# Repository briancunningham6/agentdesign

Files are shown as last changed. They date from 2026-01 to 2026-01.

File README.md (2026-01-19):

# Coffee Grounds Compost Container

A 3D-printable modular container system for collecting and draining coffee grounds, designed with CadQuery.

## Overview

This project provides a complete coffee grounds collection system with:

- **Main Container Box** (200×150×150mm) - With sloped floor and threaded drain fitting
- **Lid with Handle** - Includes integrated Nespresso capsule scraper and storage groove
- **Drain Spout** - Threaded compression fitting with TPU gasket seal
- **French Press Scraper** - Bayonet-mount scraper for cleaning French press
- **Storage Scraper** - Compact scraper that stores in the lid handle groove

All parts are designed for FDM 3D printing in PLA or PETG (except TPU gasket).

## Project Structure

```
coffee-grounds-container/
├── CAD/                    # Generated 3D model files (STL/STEP)
│   ├── box.stl
│   ├── lid.stl
│   ├── drain_spout.stl
│   └── ...
├── scripts/                # Python generator scripts
│   ├── generate_all.py
│   ├── generate_box.py
│   ├── generate_drain_spout.py
│   └── ...
├── backend/                # Flask backend (optional web interface)
├── webapp/                 # React frontend (optional web interface)
├── generate_all.sh         # Generate all CAD files
├── start_webapp.sh         # Start web interface
└── README.md
```

## Quick Start

### Generate All Parts

```bash
./generate_all.sh
```

This generates all STL and STEP files in the `CAD/` directory.

### Generate Individual Parts

```bash
# Generate box and lid
/Users/user/miniforge3/envs/cq/bin/python scripts/generate_box.py

# Generate drain spout
/Users/user/miniforge3/envs/cq/bin/python scripts/generate_drain_spout.py

# Generate French press scraper
/Users/user/miniforge3/envs/cq/bin/python scripts/generate_french_press_scraper.py

# Generate storage scraper
/Users/user/miniforge3/envs/cq/bin/python scripts/generate_storage_scraper.py
```

## Parts to Print

### Main Components (PLA/PETG)
1. **box.stl** - Main container with threaded drain boss
2. **lid.stl** - Lid with handle and integrated capsule scraper (requires nail assembly)
3. **lid_scraper.stl** - Nespresso capsule scraper (bayonet mount, alternative design)
4. **drain_spout.stl** - Threaded drain spout with hex flange
5. **french_press_scraper.stl** - French press scraper with bayonet mount
6. **storage_scraper.stl** - Compact scraper for lid storage

### Seal Component (TPU)
7. **seal_ring.stl** - Gasket for drain spout (print in TPU/NinjaFlex)

### Additional Materials Required
8. **Metal brad nails** (for lid capsule scraper)
   - 8× 1.5mm diameter × 25-30mm long brad nails (18ga)
   - See [NAIL_ASSEMBLY_GUIDE.md](NAIL_ASSEMBLY_GUIDE.md) for assembly instructions

## Print Settings

**PLA/PETG parts:**
- Layer height: 0.2mm
- Infill: 30-50%
- Wall thickness: 4 perimeters
- Top/bottom layers: 5 layers
- Supports: None needed (all parts print support-free)

**TPU gasket:**
- Layer height: 0.2mm
- Infill: 100%
- Print slowly (20-30mm/s)

## Assembly

1. **Install nails in capsule scraper (integrated into lid):**
   - Press 8× 1.5mm brad nails into holes on scraper underside
   - Nail heads sit in countersunk sockets
   - See [NAIL_ASSEMBLY_GUIDE.md](NAIL_ASSEMBLY_GUIDE.md) for detailed instructions

2. **Attach drain spout:**
   - Place TPU seal ring in the flange groove
   - Thread spout into box boss from outside
   - Hand-tighten using hex flange

3. **Attach optional scrapers to lid:**
   - **Capsule scraper (separate):** Insert shaft, rotate 60° to lock bayonet
   - **French press scraper:** Same bayonet mechanism

4. **Store scrapers when not in use:**
   - Wedge storage scraper shaft into lid handle groove
   - French press scraper can also store in groove

## Features

### Box
- 200×150×150mm interior volume
- Sloped floor (2°) drains toward left wall
- M16×3 threaded boss for secure spout attachment
- Drainage channel guides liquid to drain
- Four rubber feet recesses for stability

### Lid
- Recessed fit prevents spills
- Integrated handle with tool storage groove
- Metal nail-insert Nespresso capsule scraper (underside, requires 8× brad nails)
- Bayonet socket for attachable scrapers

### Drain Spout
- 60mm extension reaches sink
- M16×3 threaded shaft with hand-tightenable hex flange
- TPU gasket creates watertight seal
- 8mm internal bore for liquid flow

### Scrapers
- **Capsule scraper (integrated):** 8 metal nails pierce foil, rotate to extract grounds
  - Requires assembly: press 1.5mm × 25-30mm brad nails into holes
  - Metal nails are much stronger than plastic pins
- **Capsule scraper (separate, bayonet mount):** Alternative bayonet-attachable version
- **French press:** Oblong blade reaches curved areas, bayonet mount
- **Storage:** Compact design stores in handle, friction ridge locks in place

## Design Files

All scripts generate both STL (for slicing) and STEP (for CAD editing) formats.

### Test Components

Generate fit-test coupons to verify tolerances before printing full parts:

```bash
/Users/user/miniforge3/envs/cq/bin/python scripts/generate_fit_test.py
```

This creates scaled-down test pieces to verify:
- Thread engagement (spout → box)
- Bayonet lock fit (scraper → lid)
- Seal compression

## Optional Web Interface

Start the interactive web designer:

```bash
./start_webapp.sh
```

Access at http://localhost:3000 to customize dimensions and regenerate parts.

## Requirements

- **CadQuery environment:** Python with CadQuery library
- **Conda environment:** `cq` (includes CadQuery)
- **Optional:** Node.js + Flask (for web interface)

## License

Open source - modify and share freely.

## Credits

Designed with CadQuery parametric CAD library.

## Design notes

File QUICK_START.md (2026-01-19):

# Quick Start Guide

## Coffee Grounds Compost Container

### What You Need

#### To Print:
1. 3D printer (FDM recommended, PLA or PETG)
2. TPU filament (small amount for gasket)

#### To Purchase:
1. **8× Brad nails** - 1.5mm diameter × 25-30mm length (18ga)
   - Available at any hardware store
   - Used for capsule scraper assembly
   - Cost: ~$3-5 for a box of 1000

#### Tools:
- Small hammer or rubber mallet
- Hex wrench or pliers (for spout installation)

---

## Step-by-Step Instructions

### 1. Generate CAD Files

```bash
cd "/Users/user/dev/3d Models"
./generate_all.sh
```

All STL files will be created in the `CAD/` directory.

### 2. Print All Parts

Print the following files from `CAD/`:

**Main parts (PLA/PETG):**
- `box.stl` - Main container (~6-8 hours)
- `lid.stl` - Lid with integrated scraper (~2-3 hours)
- `drain_spout.stl` - Drain fitting (~1 hour)
- `storage_scraper.stl` - Scraper for French press (~1 hour)
- `french_press_scraper.stl` - Alternative scraper (~1 hour)

**Seal (TPU):**
- `seal_ring.stl` - Gasket for drain (~15 minutes)

**Print Settings:**
- Layer height: 0.2mm
- Infill: 30-50%
- Supports: NONE (all parts designed support-free)

### 3. Assemble Capsule Scraper

**The lid has 8 holes on the underside that need metal nails inserted.**

1. Flip lid upside-down
2. Locate the 8 holes on the circular scraper base
3. Take 1.5mm × 25-30mm brad nails
4. Press each nail into a hole (nail head sits in countersunk socket)
5. Tap gently with hammer until nail head is flush
6. Repeat for all 8 nails

**See [NAIL_ASSEMBLY_GUIDE.md](NAIL_ASSEMBLY_GUIDE.md) for detailed instructions with troubleshooting.**

### 4. Install Drain Spout

1. Place TPU seal ring in the groove on the underside of the hex flange
2. From outside the box, thread the spout into the threaded boss
3. Hand-tighten using the hex flange (no tools needed, but can use pliers if desired)
4. Check for watertight seal

### 5. Ready to Use!

**Using the capsule scraper:**
1. Remove used Nespresso capsule from machine
2. Center capsule on scraper (foil side up)
3. Press down firmly - metal nails pierce the foil
4. Rotate capsule 1-2 full turns
5. Lift capsule and tap to release grounds into container

**Using the French press scraper:**
1. Optional: Attach to lid using bayonet mount
2. OR use storage scraper (stores in handle groove)
3. Scrape grounds from French press into container

**Draining:**
1. Position container near sink
2. Open drain spout
3. Liquid drains out through spout
4. Coffee grounds stay in container
5. Close spout when done

---

## Troubleshooting

**Nails won't fit in holes:**
- Verify you're using 1.5mm diameter nails
- May need to pre-drill with 1.4mm bit
- Try different brand of nails (dimensions vary slightly)

**Nails pull out:**
- Use slightly thicker nails (1.6mm)
- Add tiny drop of superglue to shaft before insertion

**Spout leaks:**
- Check TPU seal ring is properly seated in groove
- Tighten spout more (hand-tight should be sufficient)
- Verify threads engaged correctly

**Lid doesn't fit:**
- Check for stringing or printing artifacts
- May need to trim the recess edges slightly
- Ensure clearances printed correctly

---

## Maintenance

**After each use:**
- Rinse container and lid
- Wipe drain spout
- Check nails are still secure

**Weekly:**
- Deep clean with dish soap
- Inspect seal ring for wear
- Check drain spout threads

**Monthly:**
- Verify all nails remain tight
- Replace any bent/damaged nails
- Check bayonet locks on scrapers

---

## Need Help?

- **Assembly issues:** See [NAIL_ASSEMBLY_GUIDE.md](NAIL_ASSEMBLY_GUIDE.md)
- **Design info:** See [README.md](README.md)
- **Changes:** See [DESIGN_CHANGELOG.md](DESIGN_CHANGELOG.md)

---

## Optional Components

The system also includes:

- `lid_scraper.stl` - Separate bayonet-mount capsule scraper (alternative to integrated version)
- `fit_test.stl` - Test coupons to verify tolerances before printing full parts
- Assembly animation frames (for documentation)

These are optional and not needed for basic operation.

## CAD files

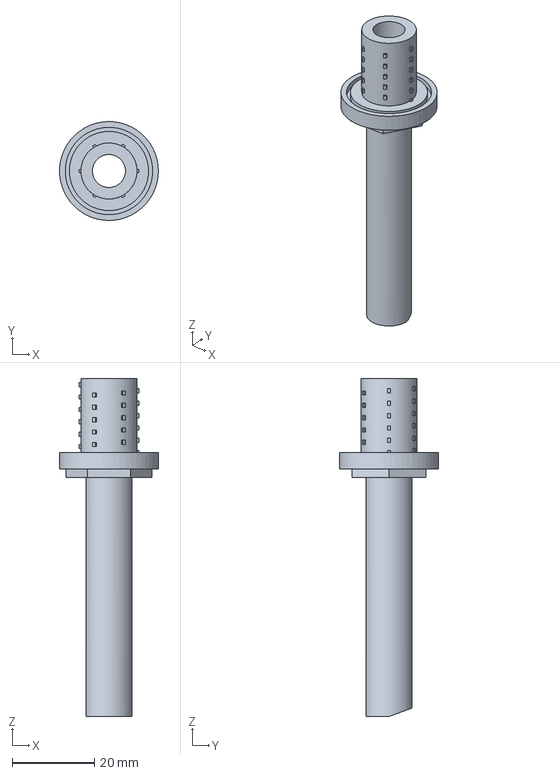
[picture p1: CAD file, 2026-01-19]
CAD/drain_spout_assembly.step
24.0 x 24.0 x 82.0 mm

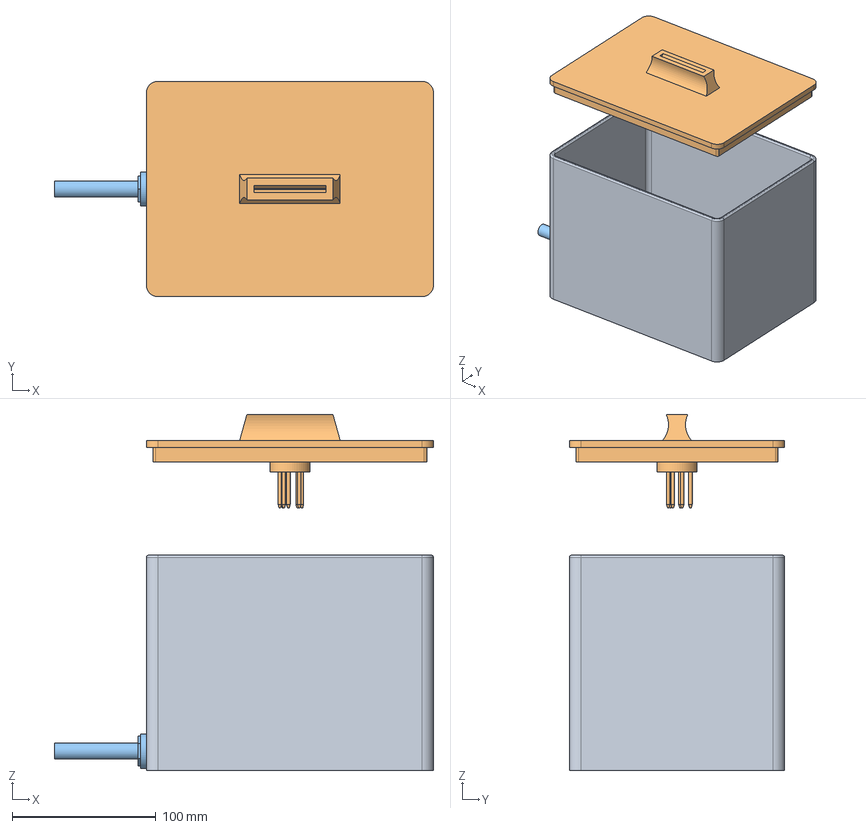
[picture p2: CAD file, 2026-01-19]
CAD/assembly.step
264.0 x 150.0 x 248.0 mm

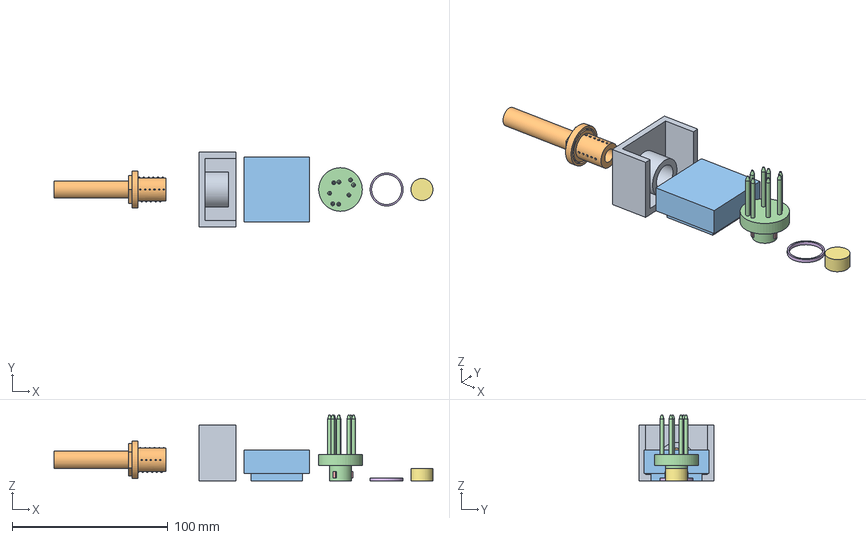
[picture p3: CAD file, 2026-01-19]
CAD/fit_test.step
243.4 x 48.0 x 42.2 mm

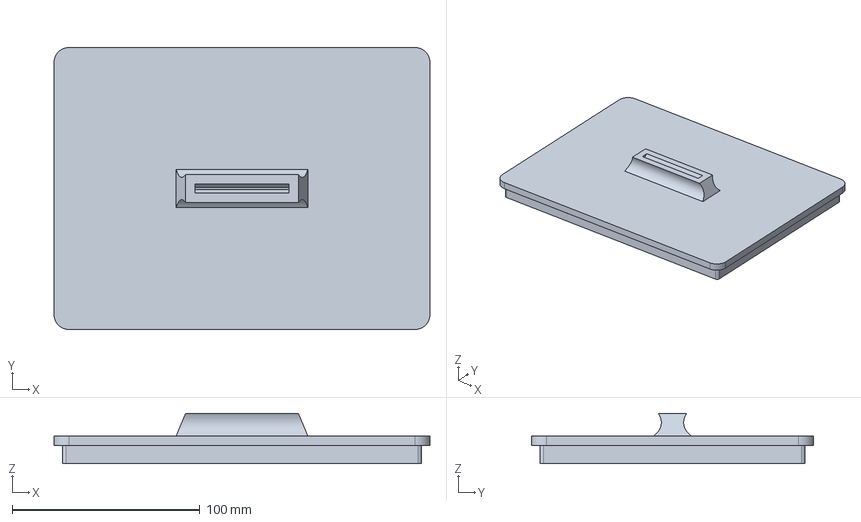
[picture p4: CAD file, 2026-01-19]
CAD/lid.step
200.0 x 150.0 x 26.8 mm

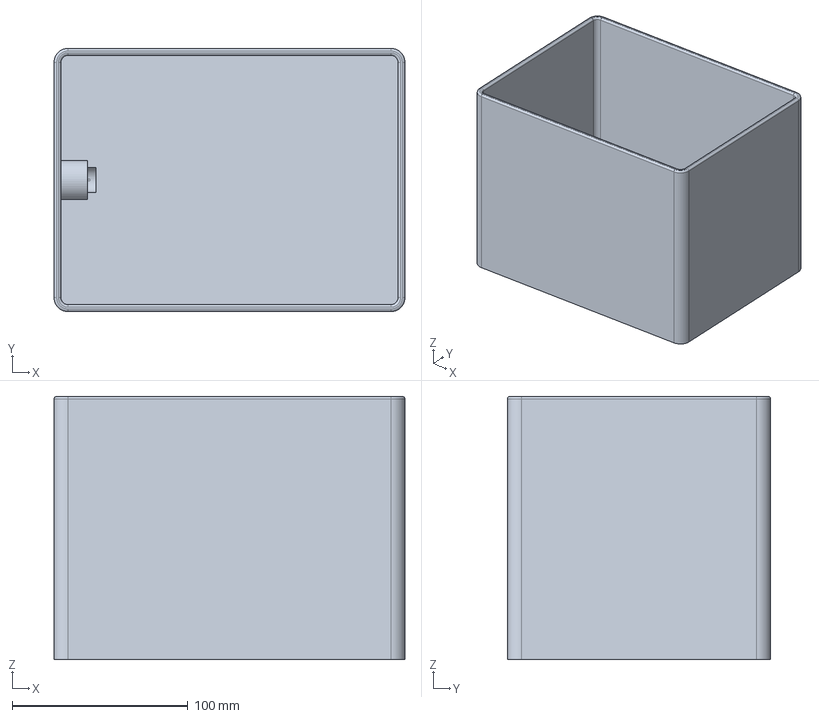
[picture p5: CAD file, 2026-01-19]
CAD/box.step
200.0 x 150.0 x 150.0 mm

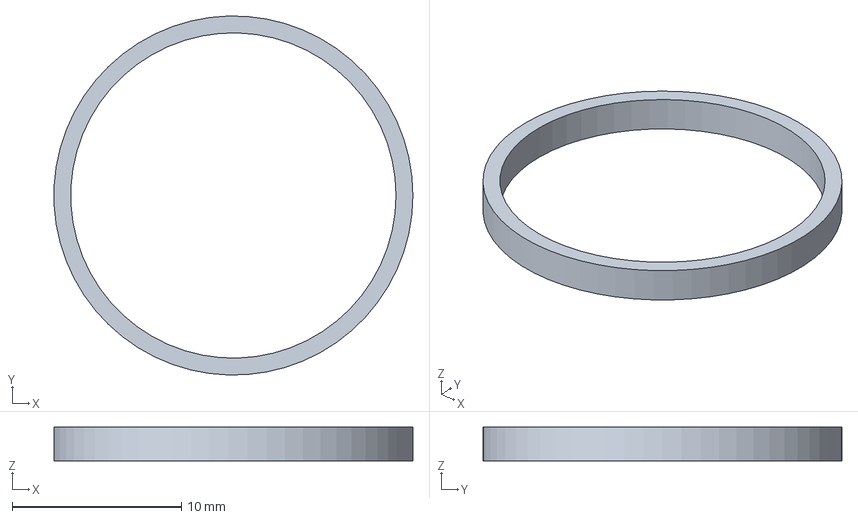
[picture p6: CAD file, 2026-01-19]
CAD/seal_ring.step
21.2 x 21.2 x 2.00 mm

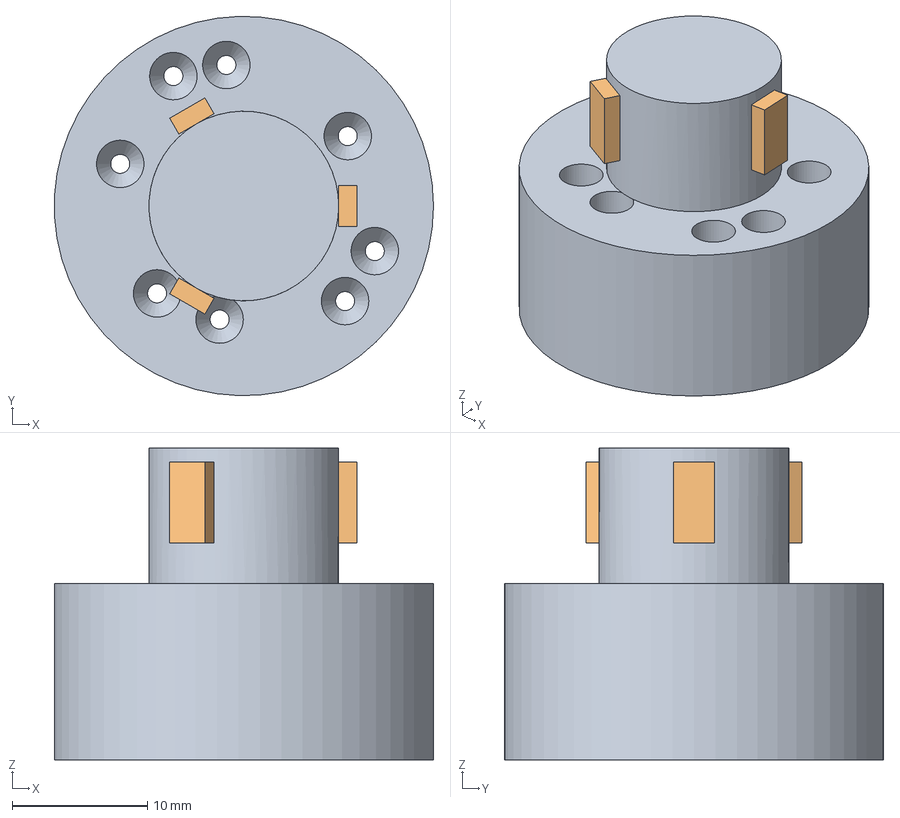
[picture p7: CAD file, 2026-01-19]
CAD/lid_scraper.step
28.0 x 28.0 x 23.0 mm

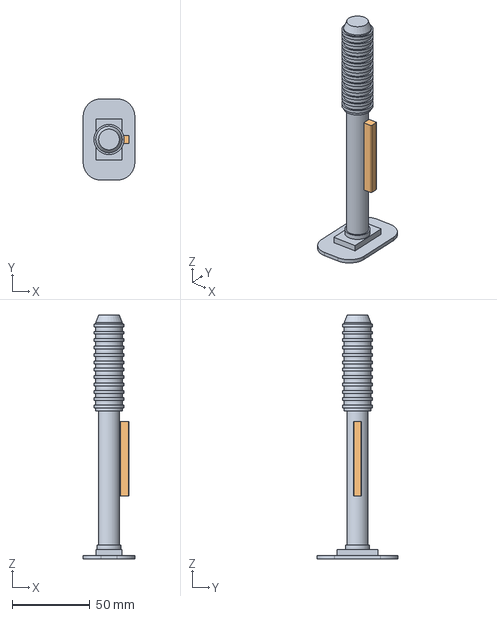
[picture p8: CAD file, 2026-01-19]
CAD/storage_scraper.step
33.2 x 52.2 x 156.9 mm

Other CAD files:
CAD/drain_spout.step
CAD/assembly.stl
CAD/box.stl
CAD/drain_spout.stl
CAD/fit_test.stl
CAD/lid.3mf
CAD/lid.stl
CAD/lid_scraper.stl
CAD/seal_ring.stl
CAD/storage_scraper.stl

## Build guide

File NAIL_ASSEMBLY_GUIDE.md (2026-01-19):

# Nespresso Capsule Scraper - Metal Nail Assembly Guide

## Overview

The capsule scraper on the underside of the lid now uses **metal nail inserts** instead of 3D-printed plastic pins. This provides much better strength and durability when piercing the aluminum foil on Nespresso capsules.

## Required Materials

### Nails (choose one type):
1. **1.5mm Brad Nails** (recommended)
   - Diameter: 1.5mm
   - Length: 25-30mm
   - Commonly available at hardware stores
   - Example: 18ga x 1" (25mm) brad nails

2. **18ga Finish Nails** (alternative)
   - Diameter: ~1.25-1.5mm
   - Length: 25-30mm
   - Slightly thinner, still works well

### Tools:
- Small hammer or rubber mallet
- Needle-nose pliers (optional, for adjustments)
- Cutting pliers or nail clippers (if nails need trimming)

## Assembly Instructions

### Step 1: Prepare the Scraper
1. Print the lid (lid.stl) which includes the integrated scraper on the underside
2. Ensure the print is clean - remove any stringing or support material from the nail holes
3. Identify the 8 nail holes on the scraper base (they have countersunk sockets)

### Step 2: Insert Nails
1. **Orientation**: Place the lid upside-down on a soft surface (towel/cloth)
2. **Insert nails from the TOP** (socket side):
   - The nail head should sit in the countersunk socket
   - The nail shaft should pass through the tight friction-fit hole
   - The nail point will extend downward from the scraper base

3. **Press-fit method**:
   - Hold nail vertically above the hole
   - Press firmly with thumb to start the nail into the socket
   - Use gentle taps with a small hammer to drive nail deeper
   - Stop when nail head is flush with or slightly below the socket surface

4. **Tight fit is intentional**:
   - The hole diameter (1.4mm) is slightly smaller than the nail (1.5mm)
   - This creates a friction fit that holds the nail securely
   - If nail is too tight, you can pre-drill with a 1.4mm bit
   - If nail is too loose, try a slightly thicker nail or add a tiny drop of superglue

### Step 3: Adjust Nail Length (if needed)
1. **Check protrusion**: Nails should extend about 25-30mm below the scraper base
2. **Trim if necessary**:
   - Use cutting pliers or nail clippers
   - Cut from the point end (not the head)
   - Leave enough length to pierce the capsule foil and reach the grounds

### Step 4: Verify Installation
1. **Check all nails are secure**:
   - Gently tug on each nail - it should not pull out
   - Nail heads should be flush or slightly recessed in sockets
   - All nails should extend approximately the same length

2. **Test the scraper**:
   - The nail points should be evenly distributed
   - Pattern should provide good coverage across the capsule diameter

## Usage

### Piercing the Capsule:
1. Remove used Nespresso capsule from machine
2. Center capsule on the scraper (foil side up)
3. Press down firmly - nails will pierce the aluminum foil
4. Rotate capsule 1-2 full turns while pressing
5. Lift capsule and shake/tap to release grounds

### Maintenance:
- Rinse scraper after use to remove coffee residue
- Check nails periodically - they should remain firmly seated
- Replace any loose or bent nails

## Troubleshooting

**Nail won't fit in hole:**
- Verify you're using 1.5mm diameter nails (or smaller)
- Pre-drill hole with 1.4mm bit if needed
- Try a different nail (some may have slightly larger heads/shafts)

**Nail pulls out easily:**
- Use slightly thicker nails (1.6mm)
- Add a tiny drop of superglue to the nail shaft before insertion
- Check that the hole printed correctly (should be 1.4mm)

**Nails bend when piercing foil:**
- Use shorter nails (25mm instead of 30mm)
- Ensure nails are steel/metal, not soft aluminum
- Press straight down, don't twist before piercing

**Nail heads stick up above surface:**
- Tap nails deeper with hammer
- Verify socket depth is sufficient (8mm)
- File/sand nail head if it's too large for socket

## Technical Specifications

**Hole Design:**
- Socket diameter: 3.5mm (captures nail head)
- Socket depth: 8mm (countersink for head)
- Shaft hole diameter: 1.4mm (friction fit for 1.5mm nail)
- Reinforcement thickness: 10mm (strong base)
- Taper: 2mm transition from socket to shaft hole

**Recommended Nails:**
- Diameter: 1.5mm (18ga)
- Length: 25-30mm
- Material: Steel (not aluminum)
- Type: Brad nails or finish nails

## Why Metal Nails?

**Advantages over plastic pins:**
- ✓ Much stronger - won't bend or break
- ✓ Sharp points easily pierce aluminum foil
- ✓ Long-lasting and durable
- ✓ Inexpensive and readily available
- ✓ Easy to replace if damaged

**Design features:**
- Countersunk sockets capture nail heads
- Tight friction fit (0.1mm interference) holds nails securely
- 10mm reinforcement base provides strength
- Tapered transition guides nails into tight shaft hole
- Semi-random pattern ensures good capsule coverage

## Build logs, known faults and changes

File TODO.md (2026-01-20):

The following design enhancements:
- Rubberised external base
- Ridge on the shaft of the scraper needs to fit into the lid handle
- Make the shaft of the scraper 1cm longer overall
- Spout should angle down 3 degrees
- Add a curve to the base of the scraper to get into the french press better
- More of an angle for the water to drain
- Better print quality on the lid
- Filter mesh to go on the top of the base to stop the spout from getting clogged
- Bayonet of the scraper not turning and locking into place
- Add a tether to the cap of the spout to the spout or find a place to store it

Web designer:
- Add option to include/remove the spout/hole

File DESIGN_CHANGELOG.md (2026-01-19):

# Design Changelog

## 2026-01-18: Metal Nail Insert Design for Capsule Scraper

### Updates (Latest):
- **Bayonet tab clearance increased**: Reduced tab protrusion from 1.5mm to 1.35mm (0.15mm reduction) to provide clearance for nail heads
- **Nail hole placement optimized**: Minimum radius increased to 8.5mm to ensure no overlap with 14mm diameter bayonet shaft
- **Through-holes verified**: Nail holes now guaranteed to pass completely through the 13mm base thickness

### Problem
The original 3D-printed plastic pins on the Nespresso capsule scraper were too weak and would bend or break when piercing the aluminum foil on capsules.

### Solution
Replaced printed plastic pins with **metal nail inserts**. The scraper base now has precision holes designed for press-fitting standard 1.5mm brad nails.

### Design Changes

#### Old Design (Plastic Pins):
- 8× 3D-printed plastic pins (2.5mm diameter)
- Tapered tips for piercing
- 4mm reinforcement base
- Pins could bend/break when piercing aluminum foil

#### New Design (Metal Nail Inserts):
- 8× holes for metal brad nails (1.5mm diameter)
- Countersunk sockets (3.5mm diameter × 8mm deep) capture nail heads
- Tight friction-fit holes (1.4mm diameter) for 1.5mm nails
- 10mm reinforcement base for added strength
- Tapered transition guides nails into shaft holes

### Technical Specifications

**Nail Specifications:**
- Type: 1.5mm diameter brad nails or 18ga finish nails
- Length: 25-30mm
- Material: Steel (not aluminum)
- Quantity: 8 nails per scraper

**Hole Design:**
```
┌─────────────┐ ← Scraper base surface (Z=0)
│   Socket    │ ← 3.5mm diameter × 8mm deep (captures nail head)
│   ●   ●     │
│    ╲ ╱      │
│     ●       │ ← 2mm taper (guides nail into shaft hole)
│     │       │
│     │       │ ← 1.4mm diameter shaft hole (friction fit)
│     │       │    Passes completely through 13mm total thickness
│     │       │    (3mm base + 10mm reinforcement)
│     ▼       │
└─────────────┘ ← Bottom surface (Z=-13mm) - hole exits here
```

**Hole Placement:**
- Minimum radius: 8.5mm (clears 14mm bayonet shaft + 1.5mm margin)
- Maximum radius: 11.2mm (SCRAPER_BASE_DIAMETER/2.5)
- Pattern: Semi-random ring distribution for even coverage

**Interference Fit:**
- Nail diameter: 1.5mm
- Hole diameter: 1.4mm
- Interference: 0.1mm (creates tight press-fit)

**Bayonet Clearance:**
- Tab protrusion: 1.35mm (reduced from 1.5mm)
- Clearance for nail heads: 0.15mm additional space

### Benefits

1. **Strength**: Metal nails are far stronger than plastic pins
2. **Durability**: Won't bend, break, or wear down
3. **Performance**: Sharp metal points easily pierce aluminum foil
4. **Cost**: Brad nails are inexpensive ($3-5 for 1000)
5. **Availability**: Standard hardware store item
6. **Replaceable**: If a nail bends, just replace it

### Assembly Required

Users must now assemble the scraper by pressing metal brad nails into the holes:

1. Print the lid (integrated scraper on underside)
2. Purchase 1.5mm × 25-30mm brad nails (8 required)
3. Press nails into holes from the socket side
4. Nail heads sit flush in countersunk sockets
5. Friction fit holds nails securely

See [NAIL_ASSEMBLY_GUIDE.md](NAIL_ASSEMBLY_GUIDE.md) for detailed assembly instructions.

### Files Modified

- `scripts/generate_box.py`:
  - Updated capsule scraper pin section (lines 57-70)
  - Changed from solid pin extrusion to hole cutting
  - Added nail socket, taper, and shaft hole geometry
  - Increased reinforcement height from 4mm to 10mm
  - Updated variable name: `scraper_with_pins` → `scraper_with_holes`
  - Updated print statements to reflect nail insert design

### Backward Compatibility

The old plastic pin design can still be regenerated by:
1. Reverting the changes in `generate_box.py`
2. OR creating a separate generator script for plastic pin version
3. OR adding a command-line flag to choose between designs

The new nail insert design is now the default.

### Testing Recommendations

1. **Print test scraper** - verify hole dimensions are correct
2. **Test nail fit** - 1.5mm brad nails should press-fit snugly
3. **Verify socket depth** - nail heads should sit flush or slightly recessed
4. **Test piercing** - metal nails should easily pierce capsule foil
5. **Check retention** - nails should not pull out under normal use

### Future Improvements

Potential enhancements:
- Add optional glue channels in sockets for permanent nail retention
- Create alternative designs for different nail sizes (1.2mm, 2.0mm)
- Design a nail insertion jig for easier assembly
- Test with different metal materials (brass, stainless steel)

---

## Previous Changes

*Add earlier design revisions here*

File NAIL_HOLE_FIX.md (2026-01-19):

# Nail Hole Design Fix - Technical Details

## Issue Identified
The original nail hole design had three problems:
1. Nail holes could overlap with the bayonet shaft (14mm diameter)
2. Bayonet tabs (1.5mm protrusion) didn't provide clearance for nail heads (3.5mm socket)
3. Nail holes might not pass completely through the base

## Solutions Implemented

### 1. Bayonet Tab Clearance
**Change:** Reduced bayonet tab protrusion by 0.15mm
- **Old value:** `BAYONET_TAB_PROTRUSION = 1.5mm`
- **New value:** `BAYONET_TAB_PROTRUSION = 1.35mm`
- **Reason:** Provides 0.15mm additional clearance for nail heads in countersunk sockets

**Impact:**
- Tabs still engage securely in bayonet slots
- Additional clearance prevents nail heads from interfering with tab rotation
- Reduces risk of nail heads catching on tabs during insertion/removal

### 2. Nail Hole Placement (No Shaft Overlap)
**Change:** Increased minimum radius to clear bayonet shaft
- **Old value:** `min_radius = SCRAPER_BASE_DIAMETER / 6` → ~4.67mm
- **New value:** `min_radius = SCRAPER_SHAFT_DIAMETER / 2 + 1.5` → 8.5mm
- **Reason:** Bayonet shaft is 14mm diameter (7mm radius), so holes must start at >7mm

**Calculation:**
```
Shaft radius:     7.0mm  (14mm diameter ÷ 2)
Safety margin:  + 1.5mm  (clearance)
─────────────────────────
Min nail radius:  8.5mm
```

**Impact:**
- Nail holes now positioned in a ring from 8.5mm to 11.2mm radius
- No overlap with central bayonet shaft
- All 8 nail holes remain visible and accessible
- Still provides good coverage across capsule area

### 3. Through-Hole Verification
**Change:** Ensured nail holes pass completely through base
- **Old calculation:** `nail_hole_length = PIN_REINFORCEMENT_HEIGHT - NAIL_SOCKET_DEPTH - NAIL_TAPER_LENGTH + 1`
- **New calculation:** Uses total base thickness with extra margin

**New Code:**
```python
total_base_thickness = SCRAPER_BASE_HEIGHT + PIN_REINFORCEMENT_HEIGHT  # 3mm + 10mm = 13mm
remaining_thickness = total_base_thickness - NAIL_SOCKET_DEPTH - NAIL_TAPER_LENGTH  # 13 - 8 - 2 = 3mm
nail_hole_length = remaining_thickness + 2  # 3 + 2 = 5mm (extra margin ensures through-hole)
```

**Depth Breakdown:**
```
Z = 0mm       ← Top surface (scraper base)
Z = -8mm      ← Socket bottom (countersink for nail head)
Z = -10mm     ← Taper bottom (transition to shaft hole)
Z = -13mm     ← Base bottom (3mm base + 10mm reinforcement)
Z = -15mm     ← Hole extends 2mm beyond (ensures through-hole)
```

**Impact:**
- Nail holes guaranteed to pass completely through
- Nails can be pushed all the way through if needed
- No blind holes that could trap nails partway
- Extra 2mm margin accounts for any printing variations

## Geometry Summary

### Scraper Base Structure:
```
                    ┌─ Bayonet shaft (14mm ø)
                    │
        ┌───────────●───────────┐
        │           │           │  ← Base surface (28mm ø)
        │  ○     ○  │  ○     ○  │  ← Nail sockets (3.5mm ø)
        │           │           │     8 holes in ring pattern
        │  ○     ○  │  ○     ○  │     Radius: 8.5mm to 11.2mm
        │           │           │
        └───────────┴───────────┘
              3mm base
        ┌─────────────────────┐
        │   PIN REINFORCEMENT  │  ← 10mm thick
        │    (solid cylinder)   │     For nail hole strength
        └─────────────────────┘
```

### Nail Hole Cross-Section:
```
        3.5mm ø socket
            ┌───┐
            │   │ 8mm deep
            │   │
            ├─┬─┤
             \│/  2mm taper
              │
              │   1.4mm ø shaft
              │   (friction fit for 1.5mm nail)
              │
              │   5mm length
              │   (passes through remaining 3mm + 2mm extra)
              ▼
```

## Verification Checklist

After regenerating, verify:

- [ ] No nail holes visible in center (within 7mm radius)
- [ ] All 8 nail holes positioned in outer ring (8.5-11.2mm radius)
- [ ] Bayonet tabs have clearance for nail head sockets
- [ ] Each hole passes completely through base (can see light through)
- [ ] Nail heads sit flush or recessed when installed
- [ ] Bayonet mechanism still functions smoothly

## Files Modified

**scripts/generate_box.py:**
- Line 89: `BAYONET_TAB_PROTRUSION = 1.35` (reduced from 1.5)
- Line 414-415: Updated min_radius calculation to clear shaft
- Line 453-461: Fixed nail hole depth calculation for through-holes

## Testing Recommendations

1. **Visual inspection:**
   - Open lid.step in CAD viewer
   - Check nail hole positions don't overlap shaft
   - Verify holes exit bottom surface

2. **Print test:**
   - Print lid
   - Check nail holes are open (not blocked)
   - Test nail insertion (should press-fit smoothly)
   - Verify bayonet shaft fits in lid socket

3. **Assembly test:**
   - Install 8× 1.5mm brad nails
   - Check nail heads sit flush in sockets
   - Attach scraper to lid using bayonet
   - Rotate to lock - should clear nail heads
   - Remove and reattach several times

## Expected Behavior

**Correct design:**
- Nail holes form a ring around the central shaft
- All holes visible and accessible from top
- Nails press-fit securely without bottoming out
- Bayonet tabs clear nail heads with 0.15mm margin
- Smooth insertion/removal of scraper from lid

**If issues persist:**
- Check SCRAPER_SHAFT_DIAMETER matches actual shaft (14mm)
- Verify min_radius calculation: should be >7mm
- Confirm total_base_thickness = 13mm
- Inspect for modeling errors in CAD viewer
